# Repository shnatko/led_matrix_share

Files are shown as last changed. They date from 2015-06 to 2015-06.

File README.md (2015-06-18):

# led_matrix_share
Eagle files for LED matrix control board / analog mux array for IR sensing

Details on the build of the LED matrix ( in coffee table form ) can be found at http://shnatko.tumblr.com

The control_FET files contain the schematic and board files for a single 8x8 common anode 8x8 RGB LED array driving via SPI 
from a microcontroller ( Arduino Due in my case ).
Multiple boards can be chained together to form larger arrays ( matrix I built using them is 16x32 )

The sense_mux files are for a second PCB used to multiplex 64 analog input signals down to 4 outputs pins for input into
the microcontroller.  Again, additional details on how it is used at http://shnatko.tumblr.com

Also included in this package is the MBI.lbr Eagle library in which I created a few components which I needed for the board layout.

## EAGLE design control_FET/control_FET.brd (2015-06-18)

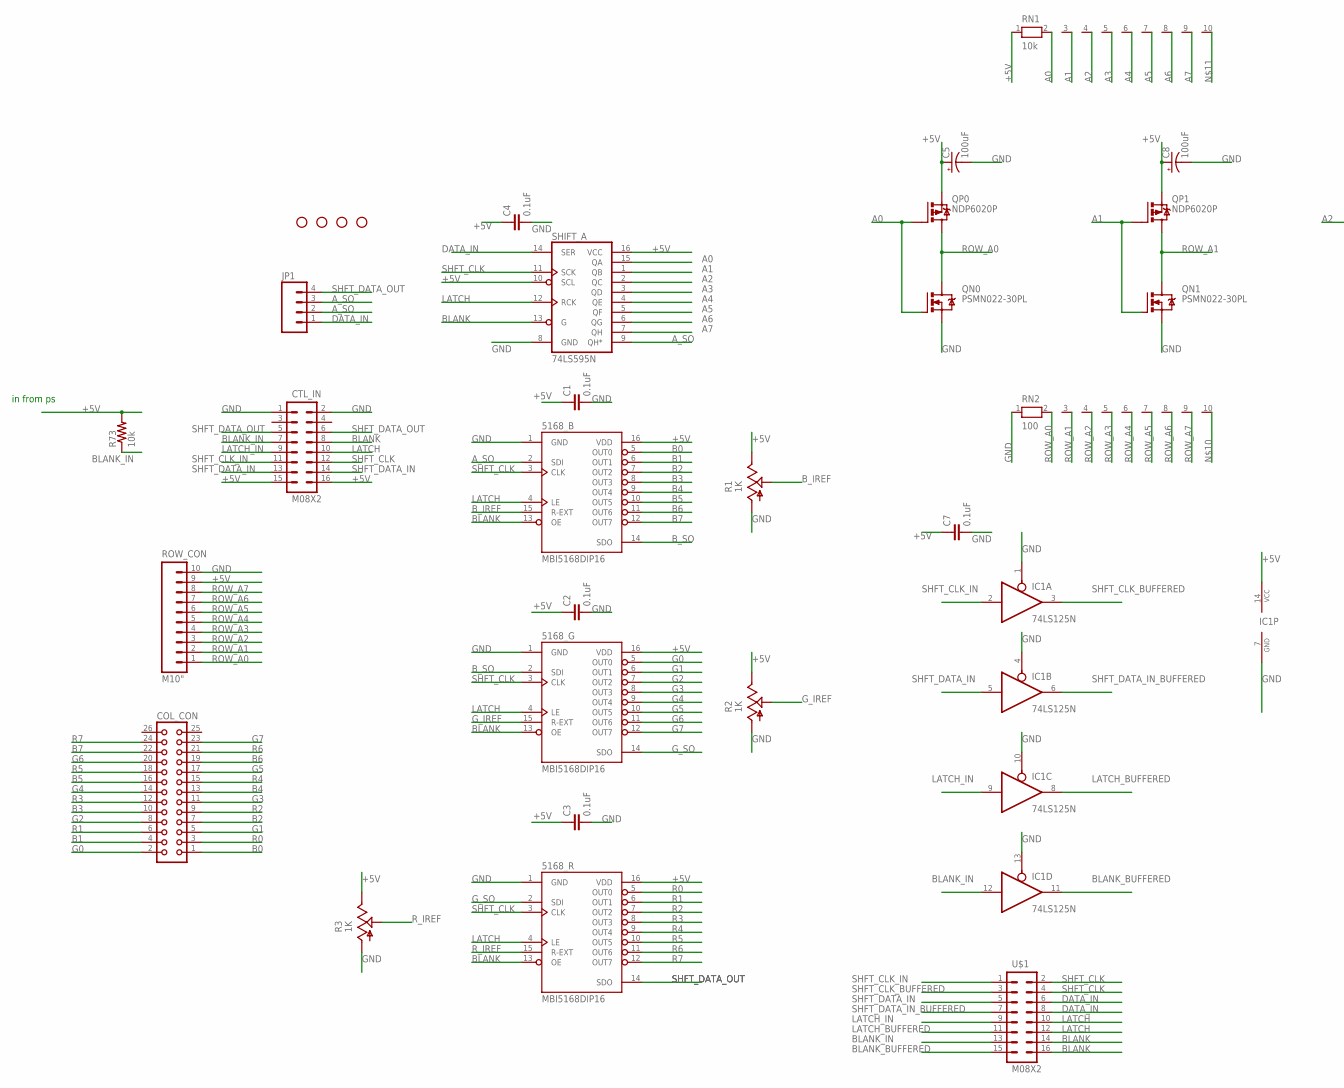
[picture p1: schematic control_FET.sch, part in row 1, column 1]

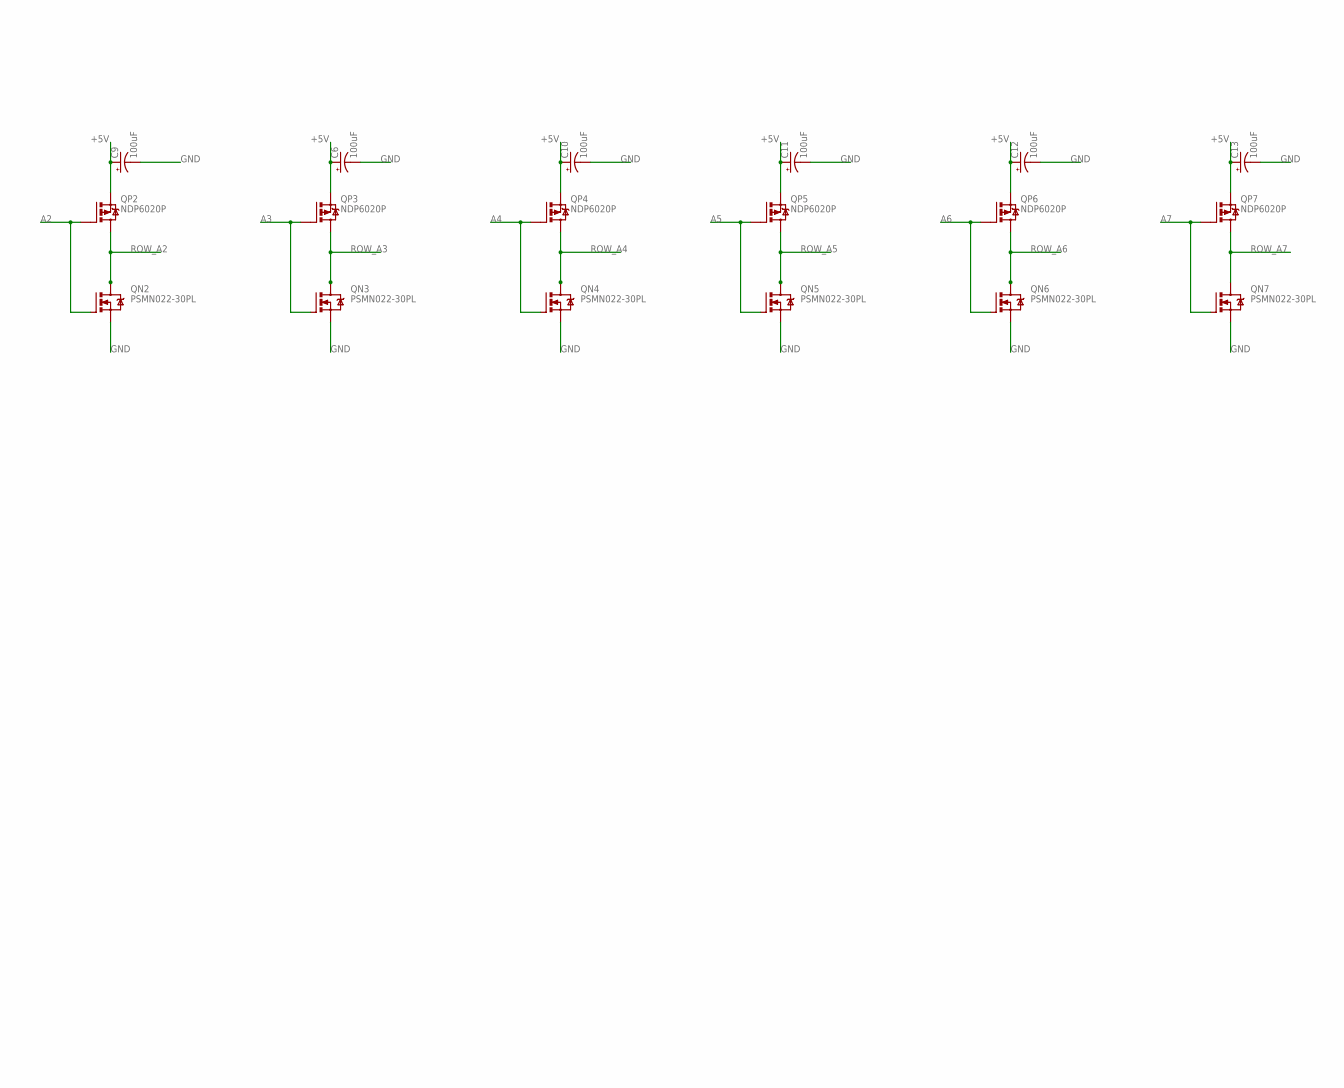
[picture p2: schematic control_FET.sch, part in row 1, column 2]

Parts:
5168_B, 5168_G, 5168_R: MBI5168DIP16; DIL16
C1, C2, C3, C4, C7: 0.1uF; C2.5-3
C5, C6, C8, C9, C10, C11, C12, C13: 100uF; CPOL-RADIAL-100UF-25V
COL_CON: CON26
CTL_IN: M08X2; 2X8
IC1: 74LS125N; DIL14
JP1: M04PTH; 1X04
QN0, QN1, QN2, QN3, QN4, QN5, QN6, QN7: PSMN022-30PL; TO220BV
QP0, QP1, QP2, QP3, QP4, QP5, QP6, QP7: NDP6020P; TO220BV
R1, R2, R3: 1K; CA6V
R73: 10k; 0207/10
RN1: 10k; RN-10
RN2: 100; RN-10
ROW_CON: M10"; 1X10
SHIFT_A: 74LS595N; DIL16
STANDOFF1, STANDOFF2, STANDOFF3, STANDOFF4: STAND-OFF
U$1: M08X2; 2X8

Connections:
+5V: 5168_B.16 (VDD), 5168_G.16 (VDD), 5168_R.16 (VDD), C1.1, C2.1, C3.1, C4.1, C5.1 (+), C6.1 (+), C7.1, C8.1 (+), C9.1 (+), C10.1 (+), C11.1 (+), C12.1 (+), C13.1 (+), CTL_IN.15, CTL_IN.16, IC1.14 (VCC), QP0.S, QP1.S, QP2.S, QP3.S, QP4.S, QP5.S, QP6.S, QP7.S, R1.E, R2.E, R3.E, R73.2, RN1.1, ROW_CON.9, SHIFT_A.10 (SCL), SHIFT_A.16 (VCC)
A0: QN0.G, QP0.G, RN1.2, SHIFT_A.15 (QA)
A1: QN1.G, QP1.G, RN1.3, SHIFT_A.1 (QB)
A2: QN2.G, QP2.G, RN1.4, SHIFT_A.2 (QC)
A3: QN3.G, QP3.G, RN1.5, SHIFT_A.3 (QD)
A4: QN4.G, QP4.G, RN1.6, SHIFT_A.4 (QE)
A5: QN5.G, QP5.G, RN1.7, SHIFT_A.5 (QF)
A6: QN6.G, QP6.G, RN1.8, SHIFT_A.6 (QG)
A7: QN7.G, QP7.G, RN1.9, SHIFT_A.7 (QH)
A_SO: 5168_B.2 (SDI), JP1.2, JP1.3, SHIFT_A.9 (QH*)
B0: 5168_B.5 (OUT0), COL_CON.1
B1: 5168_B.6 (OUT1), COL_CON.4
B2: 5168_B.7 (OUT2), COL_CON.7
B3: 5168_B.8 (OUT3), COL_CON.10
B4: 5168_B.9 (OUT4), COL_CON.13
B5: 5168_B.10 (OUT5), COL_CON.16
B6: 5168_B.11 (OUT6), COL_CON.19
B7: 5168_B.12 (OUT7), COL_CON.22
BLANK: 5168_B.13 (OE), 5168_G.13 (OE), 5168_R.13 (OE), CTL_IN.8, SHIFT_A.13 (G), U$1.14, U$1.16
BLANK_BUFFERED: IC1.11 (O), U$1.15
BLANK_IN: CTL_IN.7, IC1.12 (I), R73.1, U$1.13
B_IREF: 5168_B.15 (R-EXT), R1.S
B_SO: 5168_B.14 (SDO), 5168_G.2 (SDI)
DATA_IN: JP1.1, SHIFT_A.14 (SER), U$1.6, U$1.8
G0: 5168_G.5 (OUT0), COL_CON.2
G1: 5168_G.6 (OUT1), COL_CON.5
G2: 5168_G.7 (OUT2), COL_CON.8
G3: 5168_G.8 (OUT3), COL_CON.11
G4: 5168_G.9 (OUT4), COL_CON.14
G5: 5168_G.10 (OUT5), COL_CON.17
G6: 5168_G.11 (OUT6), COL_CON.20
G7: 5168_G.12 (OUT7), COL_CON.23
GND: 5168_B.1 (GND), 5168_G.1 (GND), 5168_R.1 (GND), C1.2, C2.2, C3.2, C4.2, C5.2 (-), C6.2 (-), C7.2, C8.2 (-), C9.2 (-), C10.2 (-), C11.2 (-), C12.2 (-), C13.2 (-), CTL_IN.1, CTL_IN.2, IC1.1 (OE), IC1.4 (OE), IC1.7 (GND), IC1.10 (OE), IC1.13 (OE), QN0.S, QN1.S, QN2.S, QN3.S, QN4.S, QN5.S, QN6.S, QN7.S, R1.A, R2.A, R3.A, RN2.1, ROW_CON.10, SHIFT_A.8 (GND)
G_IREF: 5168_G.15 (R-EXT), R2.S
G_SO: 5168_G.14 (SDO), 5168_R.2 (SDI)
LATCH: 5168_B.4 (LE), 5168_G.4 (LE), 5168_R.4 (LE), CTL_IN.10, SHIFT_A.12 (RCK), U$1.10, U$1.12
LATCH_BUFFERED: IC1.8 (O), U$1.11
LATCH_IN: CTL_IN.9, IC1.9 (I), U$1.9
R0: 5168_R.5 (OUT0), COL_CON.3
R1: 5168_R.6 (OUT1), COL_CON.6
R2: 5168_R.7 (OUT2), COL_CON.9
R3: 5168_R.8 (OUT3), COL_CON.12
R4: 5168_R.9 (OUT4), COL_CON.15
R5: 5168_R.10 (OUT5), COL_CON.18
R6: 5168_R.11 (OUT6), COL_CON.21
R7: 5168_R.12 (OUT7), COL_CON.24
ROW_A0: QN0.D, QP0.D, RN2.2, ROW_CON.1
ROW_A1: QN1.D, QP1.D, RN2.3, ROW_CON.2
ROW_A2: QN2.D, QP2.D, RN2.4, ROW_CON.3
ROW_A3: QN3.D, QP3.D, RN2.5, ROW_CON.4
ROW_A4: QN4.D, QP4.D, RN2.6, ROW_CON.5
ROW_A5: QN5.D, QP5.D, RN2.7, ROW_CON.6
ROW_A6: QN6.D, QP6.D, RN2.8, ROW_CON.7
ROW_A7: QN7.D, QP7.D, RN2.9, ROW_CON.8
R_IREF: 5168_R.15 (R-EXT), R3.S
SHFT_CLK: 5168_B.3 (CLK), 5168_G.3 (CLK), 5168_R.3 (CLK), CTL_IN.12, SHIFT_A.11 (SCK), U$1.2, U$1.4
SHFT_CLK_BUFFERED: IC1.3 (O), U$1.3
SHFT_CLK_IN: CTL_IN.11, IC1.2 (I), U$1.1
SHFT_DATA_IN: CTL_IN.13, CTL_IN.14, IC1.5 (I), U$1.5
SHFT_DATA_IN_BUFFERED: IC1.6 (O), U$1.7
SHFT_DATA_OUT: 5168_R.14 (SDO), CTL_IN.5, CTL_IN.6, JP1.4

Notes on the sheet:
in from ps

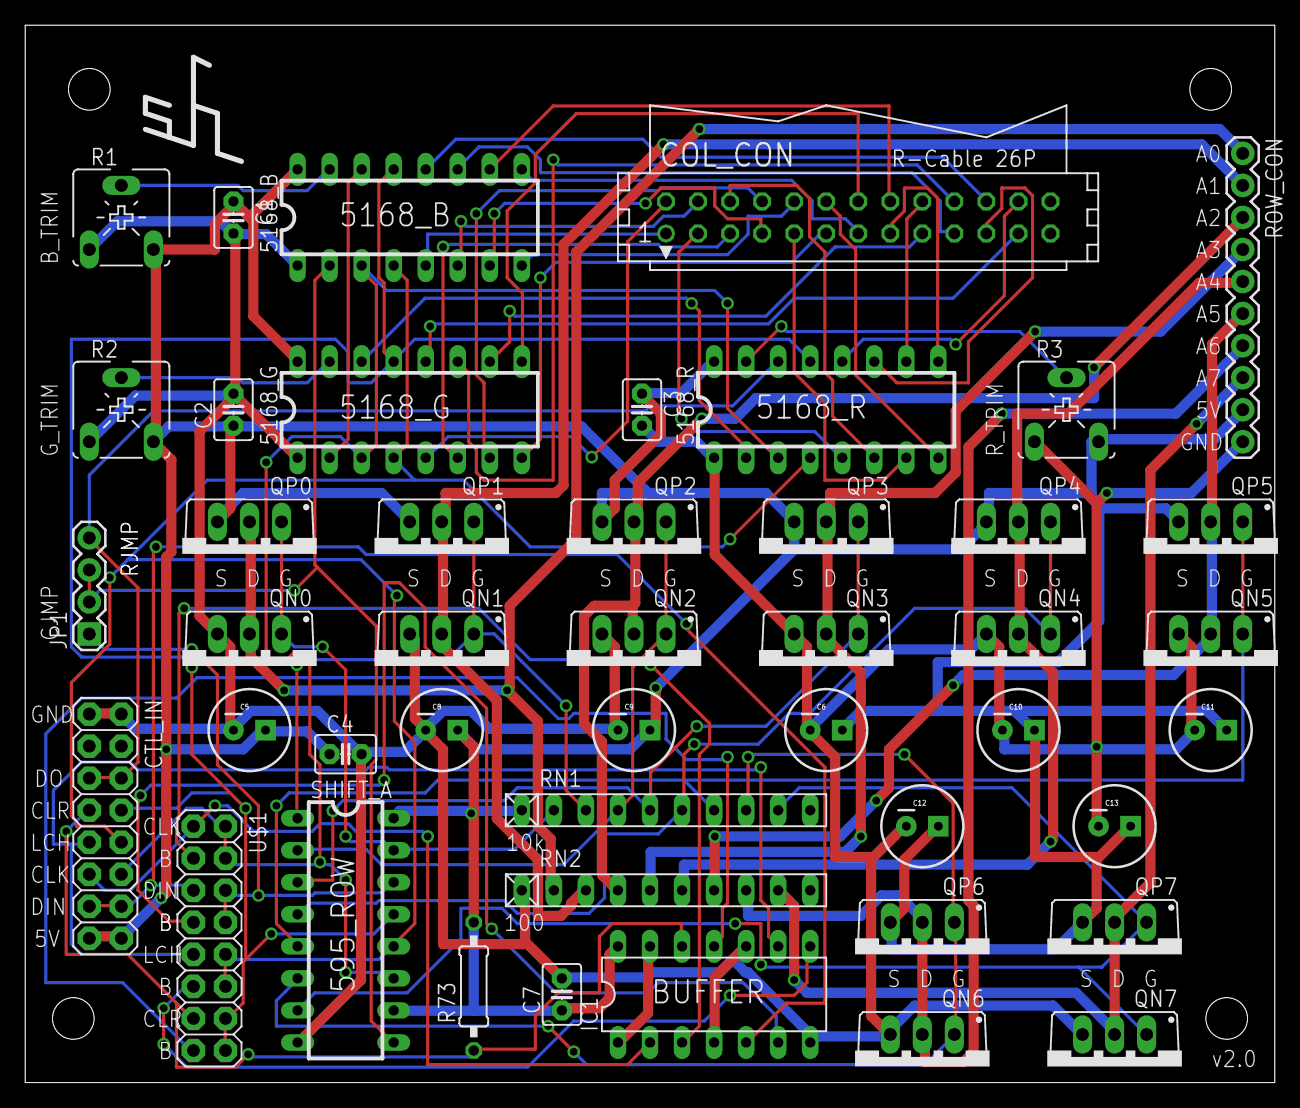
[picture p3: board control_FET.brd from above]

Board: 2 copper layers, 99.1 x 83.8 mm, 49 parts (0 on the bottom side), 61 nets.

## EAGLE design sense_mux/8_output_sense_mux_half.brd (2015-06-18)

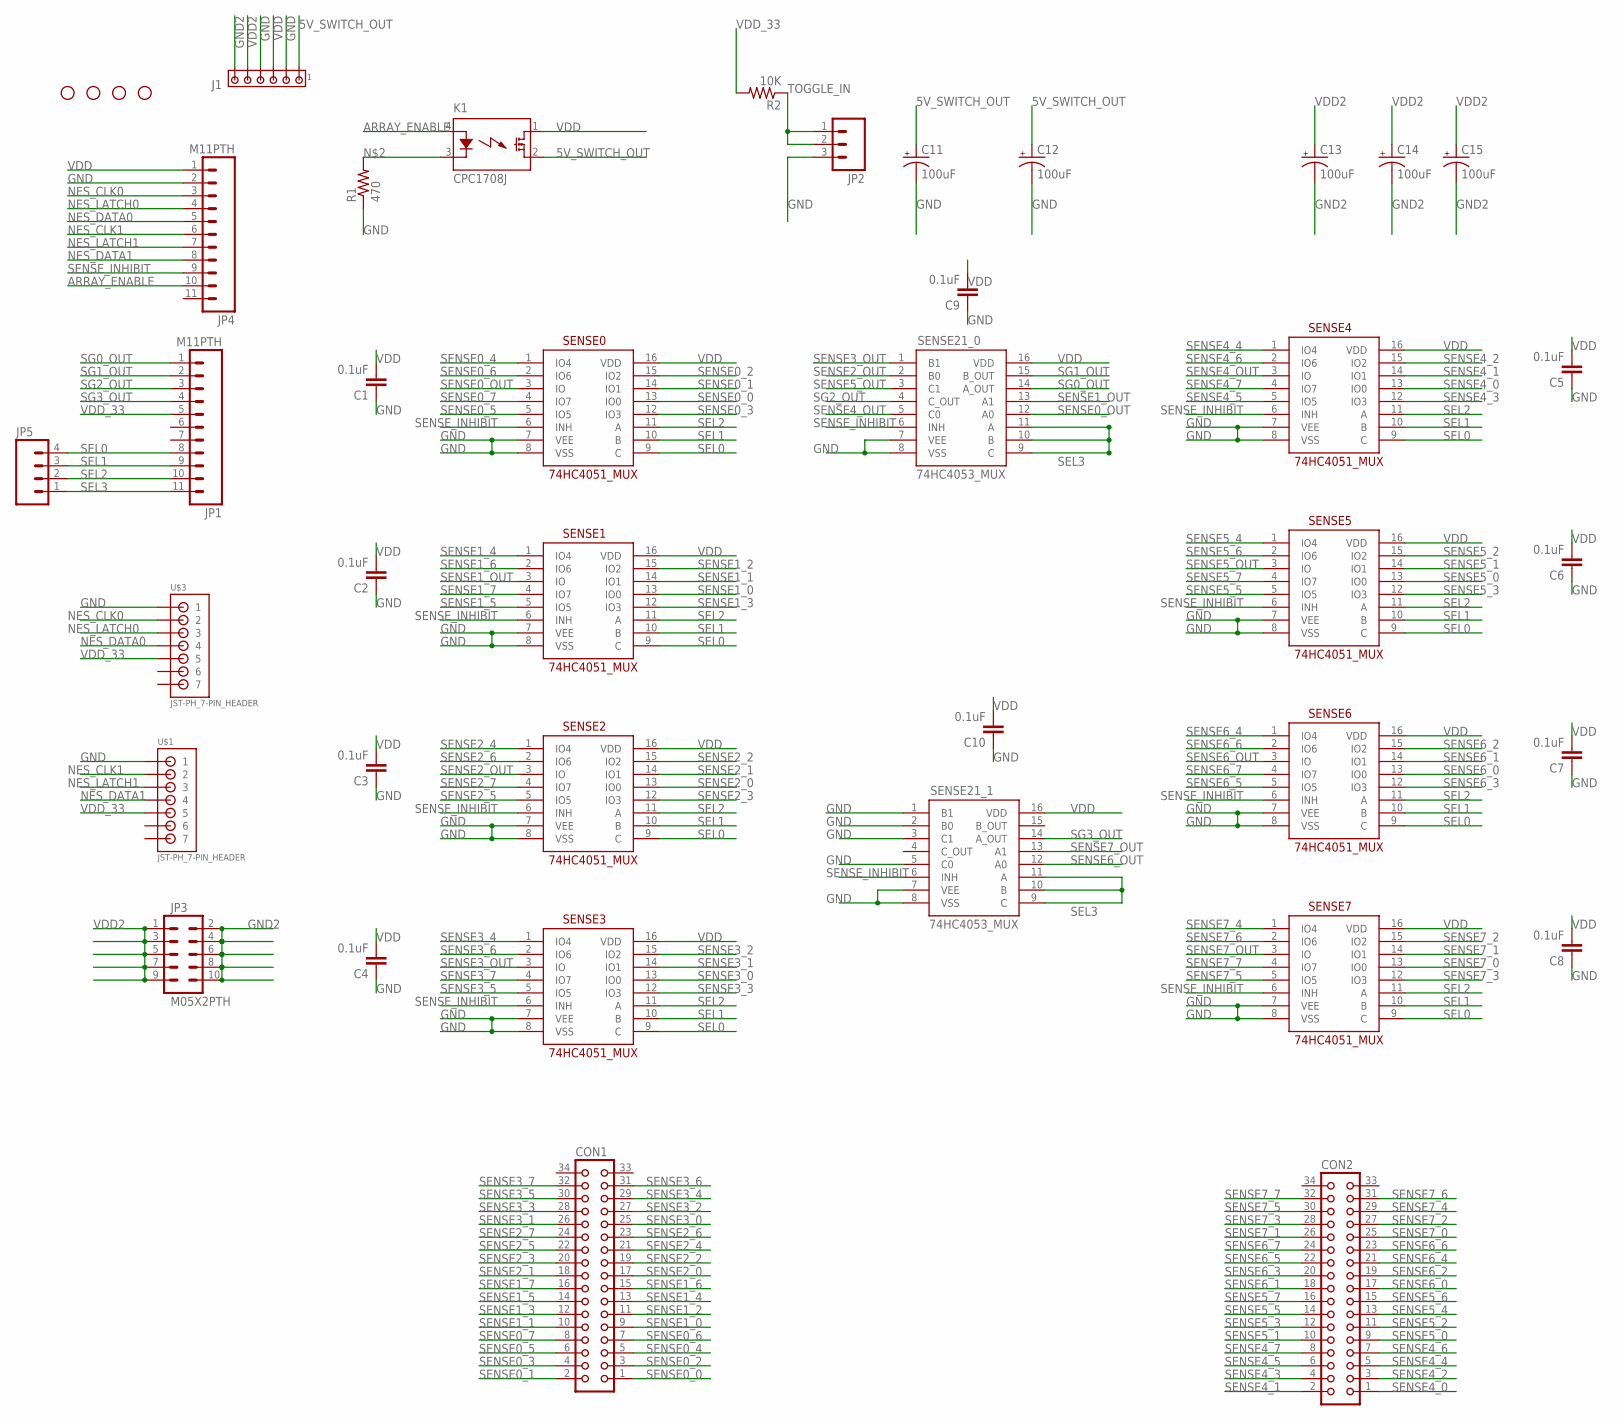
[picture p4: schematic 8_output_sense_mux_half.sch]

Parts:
C1, C2, C3, C4, C5, C6, C7, C8, C9, C10: 0.1uF; C2.5-3
C11, C12, C13, C14, C15: 100uF; CPOL-RADIAL-100UF-25V
CON1, CON2: CON34
J1: MTA06-156; 1X6MTA
JP1, JP4: M11PTH; 1X11
JP2: M03PTH; 1X03
JP3: M05X2PTH; AVR_ICSP
JP5: M04PTH; 1X04
K1: CPC1708J; I4-PAC
R1: 470; AXIAL-0.3-KIT
R2: 10K; AXIAL-0.3-KIT
SENSE0, SENSE1, SENSE2, SENSE3, SENSE4, SENSE5, SENSE6, SENSE7: 74HC4051_MUX; DIL16
SENSE21_0, SENSE21_1: 74HC4053_MUX; DIL16
STANDOFF1, STANDOFF2, STANDOFF3, STANDOFF4: STAND-OFF
U$1, U$3: JST-PH_7-PIN_HEADER; JST_B7B-PH_HEADER

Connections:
5V_SWITCH_OUT: C11.1 (+), C12.1 (+), J1.1, K1.2 (DS2)
ARRAY_ENABLE: JP4.10, K1.4 (A)
GND: C1.1, C2.1, C3.1, C4.1, C5.1, C6.1, C7.1, C8.1, C9.1, C10.1, C11.2 (-), C12.2 (-), J1.2, J1.4, JP2.3, JP4.2, R1.P$1 (1), SENSE0.7 (VEE), SENSE0.8 (VSS), SENSE1.7 (VEE), SENSE1.8 (VSS), SENSE2.7 (VEE), SENSE2.8 (VSS), SENSE3.7 (VEE), SENSE3.8 (VSS), SENSE4.7 (VEE), SENSE4.8 (VSS), SENSE5.7 (VEE), SENSE5.8 (VSS), SENSE6.7 (VEE), SENSE6.8 (VSS), SENSE7.7 (VEE), SENSE7.8 (VSS), SENSE21_0.7 (VEE), SENSE21_0.8 (VSS), SENSE21_1.1 (B1), SENSE21_1.2 (B0), SENSE21_1.3 (C1), SENSE21_1.5 (C0), SENSE21_1.7 (VEE), SENSE21_1.8 (VSS), U$1.P1 (1), U$3.P1 (1)
GND2: C13.2 (-), C14.2 (-), C15.2 (-), J1.6, JP3.2, JP3.4, JP3.6, JP3.8, JP3.10
unnamed: K1.3 (K), R1.P$2 (2)
NES_CLK0: JP4.3, U$3.P2 (2)
NES_CLK1: JP4.6, U$1.P2 (2)
NES_DATA0: JP4.5, U$3.P4 (4)
NES_DATA1: JP4.8, U$1.P4 (4)
NES_LATCH0: JP4.4, U$3.P3 (3)
NES_LATCH1: JP4.7, U$1.P3 (3)
SEL0: JP1.8, JP5.4, SENSE0.9 (C), SENSE1.9 (C), SENSE2.9 (C), SENSE3.9 (C), SENSE4.9 (C), SENSE5.9 (C), SENSE6.9 (C), SENSE7.9 (C)
SEL1: JP1.9, JP5.3, SENSE0.10 (B), SENSE1.10 (B), SENSE2.10 (B), SENSE3.10 (B), SENSE4.10 (B), SENSE5.10 (B), SENSE6.10 (B), SENSE7.10 (B)
SEL2: JP1.10, JP5.2, SENSE0.11 (A), SENSE1.11 (A), SENSE2.11 (A), SENSE3.11 (A), SENSE4.11 (A), SENSE5.11 (A), SENSE6.11 (A), SENSE7.11 (A)
SEL3: JP1.11, JP5.1, SENSE21_0.9 (C), SENSE21_0.10 (B), SENSE21_0.11 (A), SENSE21_1.9 (C), SENSE21_1.10 (B), SENSE21_1.11 (A)
SENSE0_0: CON1.1, SENSE0.13 (IO0)
SENSE0_1: CON1.2, SENSE0.14 (IO1)
SENSE0_2: CON1.3, SENSE0.15 (IO2)
SENSE0_3: CON1.4, SENSE0.12 (IO3)
SENSE0_4: CON1.5, SENSE0.1 (IO4)
SENSE0_5: CON1.6, SENSE0.5 (IO5)
SENSE0_6: CON1.7, SENSE0.2 (IO6)
SENSE0_7: CON1.8, SENSE0.4 (IO7)
SENSE0_OUT: SENSE0.3 (IO), SENSE21_0.12 (A0)
SENSE1_0: CON1.9, SENSE1.13 (IO0)
SENSE1_1: CON1.10, SENSE1.14 (IO1)
SENSE1_2: CON1.11, SENSE1.15 (IO2)
SENSE1_3: CON1.12, SENSE1.12 (IO3)
SENSE1_4: CON1.13, SENSE1.1 (IO4)
SENSE1_5: CON1.14, SENSE1.5 (IO5)
SENSE1_6: CON1.15, SENSE1.2 (IO6)
SENSE1_7: CON1.16, SENSE1.4 (IO7)
SENSE1_OUT: SENSE1.3 (IO), SENSE21_0.13 (A1)
SENSE2_0: CON1.17, SENSE2.13 (IO0)
SENSE2_1: CON1.18, SENSE2.14 (IO1)
SENSE2_2: CON1.19, SENSE2.15 (IO2)
SENSE2_3: CON1.20, SENSE2.12 (IO3)
SENSE2_4: CON1.21, SENSE2.1 (IO4)
SENSE2_5: CON1.22, SENSE2.5 (IO5)
SENSE2_6: CON1.23, SENSE2.2 (IO6)
SENSE2_7: CON1.24, SENSE2.4 (IO7)
SENSE2_OUT: SENSE2.3 (IO), SENSE21_0.2 (B0)
SENSE3_0: CON1.25, SENSE3.13 (IO0)
SENSE3_1: CON1.26, SENSE3.14 (IO1)
SENSE3_2: CON1.27, SENSE3.15 (IO2)
SENSE3_3: CON1.28, SENSE3.12 (IO3)
SENSE3_4: CON1.29, SENSE3.1 (IO4)
SENSE3_5: CON1.30, SENSE3.5 (IO5)
SENSE3_6: CON1.31, SENSE3.2 (IO6)
SENSE3_7: CON1.32, SENSE3.4 (IO7)
SENSE3_OUT: SENSE3.3 (IO), SENSE21_0.1 (B1)
SENSE4_0: CON2.1, SENSE4.13 (IO0)
SENSE4_1: CON2.2, SENSE4.14 (IO1)
SENSE4_2: CON2.3, SENSE4.15 (IO2)
SENSE4_3: CON2.4, SENSE4.12 (IO3)
SENSE4_4: CON2.5, SENSE4.1 (IO4)
SENSE4_5: CON2.6, SENSE4.5 (IO5)
SENSE4_6: CON2.7, SENSE4.2 (IO6)
SENSE4_7: CON2.8, SENSE4.4 (IO7)
SENSE4_OUT: SENSE4.3 (IO), SENSE21_0.5 (C0)
SENSE5_0: CON2.9, SENSE5.13 (IO0)
SENSE5_1: CON2.10, SENSE5.14 (IO1)
SENSE5_2: CON2.11, SENSE5.15 (IO2)
SENSE5_3: CON2.12, SENSE5.12 (IO3)
SENSE5_4: CON2.13, SENSE5.1 (IO4)
SENSE5_5: CON2.14, SENSE5.5 (IO5)
SENSE5_6: CON2.15, SENSE5.2 (IO6)
SENSE5_7: CON2.16, SENSE5.4 (IO7)
SENSE5_OUT: SENSE5.3 (IO), SENSE21_0.3 (C1)
SENSE6_0: CON2.17, SENSE6.13 (IO0)
SENSE6_1: CON2.18, SENSE6.14 (IO1)
SENSE6_2: CON2.19, SENSE6.15 (IO2)
SENSE6_3: CON2.20, SENSE6.12 (IO3)
SENSE6_4: CON2.21, SENSE6.1 (IO4)
SENSE6_5: CON2.22, SENSE6.5 (IO5)
SENSE6_6: CON2.23, SENSE6.2 (IO6)
SENSE6_7: CON2.24, SENSE6.4 (IO7)
SENSE6_OUT: SENSE6.3 (IO), SENSE21_1.12 (A0)
SENSE7_0: CON2.25, SENSE7.13 (IO0)
SENSE7_1: CON2.26, SENSE7.14 (IO1)
SENSE7_2: CON2.27, SENSE7.15 (IO2)
SENSE7_3: CON2.28, SENSE7.12 (IO3)
SENSE7_4: CON2.29, SENSE7.1 (IO4)
SENSE7_5: CON2.30, SENSE7.5 (IO5)
SENSE7_6: CON2.31, SENSE7.2 (IO6)
SENSE7_7: CON2.32, SENSE7.4 (IO7)
SENSE7_OUT: SENSE7.3 (IO), SENSE21_1.13 (A1)
SENSE_INHIBIT: JP4.9, SENSE0.6 (INH), SENSE1.6 (INH), SENSE2.6 (INH), SENSE3.6 (INH), SENSE4.6 (INH), SENSE5.6 (INH), SENSE6.6 (INH), SENSE7.6 (INH), SENSE21_0.6 (INH), SENSE21_1.6 (INH)
SG0_OUT: JP1.1, SENSE21_0.14 (A_OUT)
SG1_OUT: JP1.2, SENSE21_0.15 (B_OUT)
SG2_OUT: JP1.3, SENSE21_0.4 (C_OUT)
SG3_OUT: JP1.4, SENSE21_1.14 (A_OUT)
TOGGLE_IN: JP2.1, JP2.2, R2.P$1 (1)
VDD: C1.2, C2.2, C3.2, C4.2, C5.2, C6.2, C7.2, C8.2, C9.2, C10.2, J1.3, JP4.1, K1.1 (DS1), SENSE0.16 (VDD), SENSE1.16 (VDD), SENSE2.16 (VDD), SENSE3.16 (VDD), SENSE4.16 (VDD), SENSE5.16 (VDD), SENSE6.16 (VDD), SENSE7.16 (VDD), SENSE21_0.16 (VDD), SENSE21_1.16 (VDD)
VDD2: C13.1 (+), C14.1 (+), C15.1 (+), J1.5, JP3.1, JP3.3, JP3.5, JP3.7, JP3.9
VDD_33: JP1.5, R2.P$2 (2), U$1.P5 (5), U$3.P5 (5)

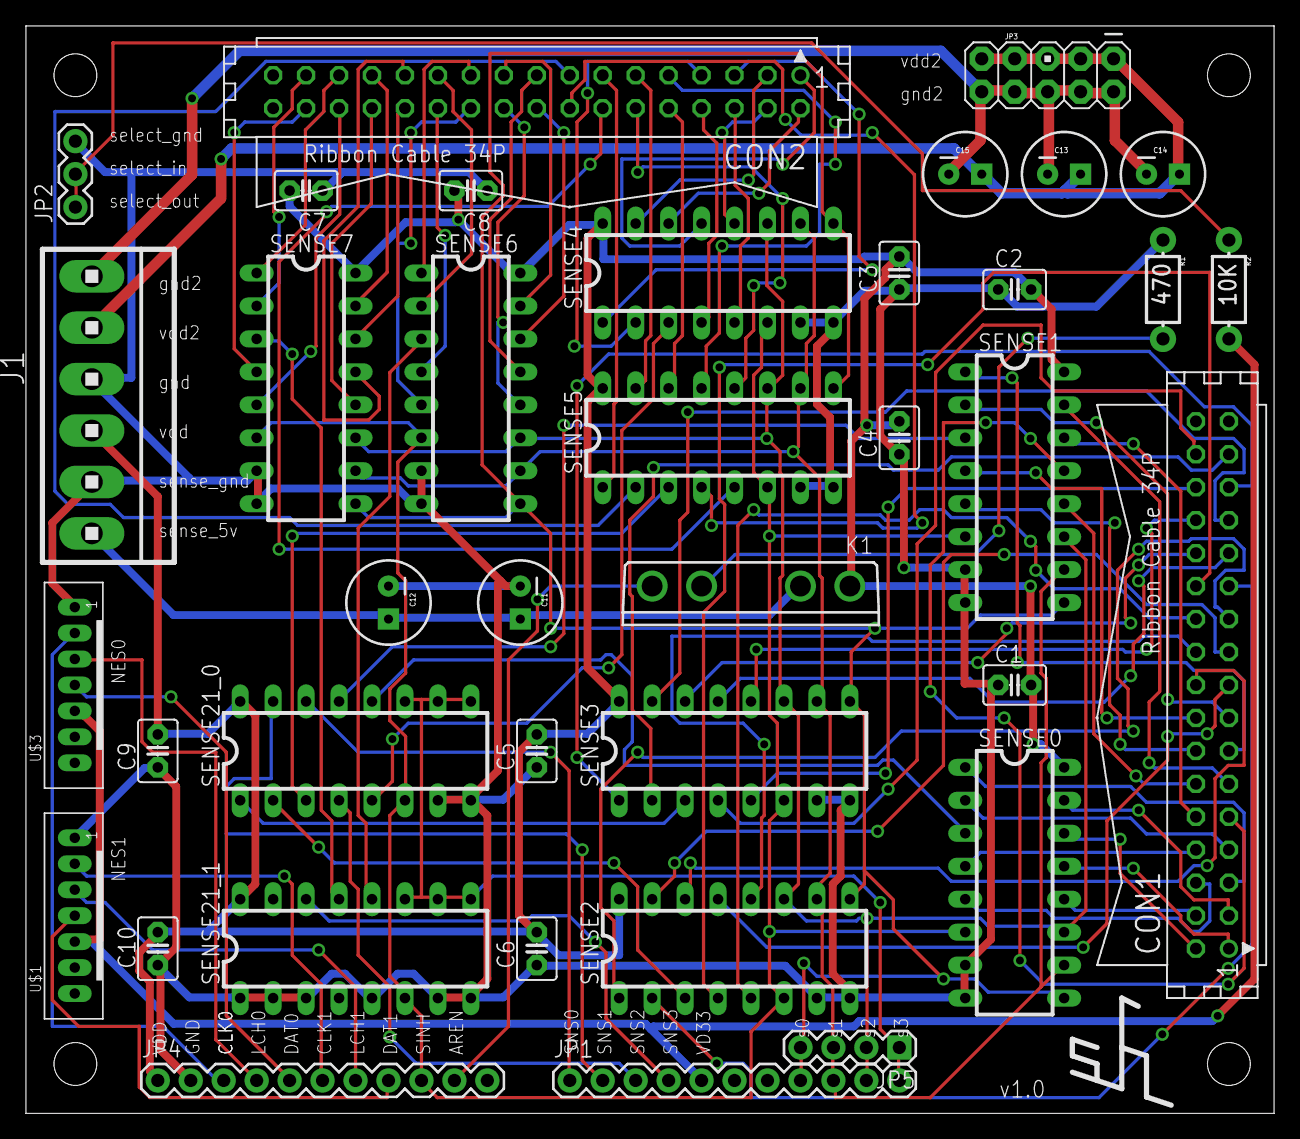
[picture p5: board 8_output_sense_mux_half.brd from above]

Board: 2 copper layers, 96.2 x 83.8 mm, 43 parts (0 on the bottom side), 96 nets.

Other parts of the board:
U$2: SH

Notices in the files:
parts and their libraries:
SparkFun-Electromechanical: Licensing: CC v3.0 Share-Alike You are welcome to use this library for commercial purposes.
